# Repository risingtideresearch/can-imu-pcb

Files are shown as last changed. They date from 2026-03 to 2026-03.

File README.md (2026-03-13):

# CAN IMU

A carrier PCB for a Microstrain 3DM-CV7 Inertial Measurement Unit to act as a CAN / NMEA 2000
device.

It is designed to fit in the Hammond [1554E2GY](https://www.hammfg.com/part/1554E2GY) enclosure.

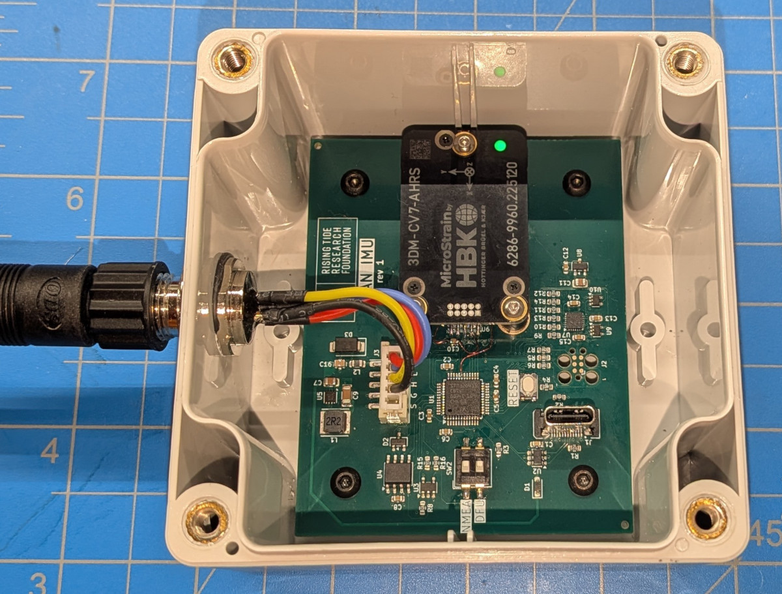
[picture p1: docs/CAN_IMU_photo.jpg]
CAN IMU CANIMU


## Assembly

The BOM can be found [here](output/CAN_IMU_rev1_BOM.csv), and includes most parts, but there are
some additional parts not included there:

- The case: Hammond 1554E2GY
- Brass solderable nuts for securing the microstrain: SMTSOB-256-2ET (qty 3)
- M3x8 screws for securing the PCB in the enclosure (These should ideally be non-ferrous if you care about magnetemeter accuracy) 
- M12 connector: [T4130012051-000](https://www.digikey.com/en/products/detail/te-connectivity-amp-connectors/T4130012051-000/7927438)
- 5-pin PH connector housing for wiring the M12 to the board:
  [PHR-5](https://www.digikey.com/en/products/detail/jst-sales-america-inc/PHR-5/608605) (plus the
  appropriate crimp pins or pre-crimped wires)

## Software

Software for this board can be found in the [can-imu-fw repo](https://github.com/risingtideresearch/can-imu-fw)

# Revision History

## Rev 1

First fabricated January 2026. 

### Errata

- The microstrain IMU connector is backwards (repairable with cut traces and bodge wires)

## Rev 2

Fixes IMU connector pinout. No CPU pin changes, and functionally equivalent to bodged rev1.

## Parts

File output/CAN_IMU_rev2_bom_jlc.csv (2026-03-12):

Designator | Footprint | Quantity | Value | LCSC Part #
C1 | 0603 | 1 | 0.1u | C1590
C10, C12, C13, C14, C15, C2, C3, C4, C5, C6, C8 | 0603 | 11 | 1u | C15849
C11, C7 | 0805 | 2 | 10uF | C15850
C16 | NFM21PC_Feedthrough_Cap | 1 | NFM21PC104R1E3D | C86150
C9 | 1206 | 1 | 22uF | C12891
D1 | D_SOD-323_HandSoldering | 1 | CUS10S30,H3F | C146335
D2 | SOT-23 | 1 | ESD2CANFD24 | C5278878
D3 | D_SMA | 1 | SMAJ17A-13-F | C134963
J1 | USB_C_Receptacle_JAE_DX07S024WJ3R400 | 1 | USB_C_Receptacle_USB2.0_16P | C2896636
J3 | JST_PH_B5B-PH-SM4-TB_1x05-1MP_P2.00mm_Vertical | 1 | Conn_01x05 | C265085
L1 | IND_LQH5BPN2R2NT0L | 1 | 2.2uH | C135262
L2 | 0805 | 1 | MPZ2012S601AT000 | C21519
R1, R10, R11, R12, R13, R14, R16, R2, R9 | 0603 | 9 | 5.1k | C105580
R15, R3, R8 | 0603 | 3 | 47k | C25819
R4, R5, R6, R7 | 0603 | 4 | 100 | C105588
SW1 | SW_SPST_PTS810 | 1 | RST | C221896
SW2 | SW_DIP_SPSTx02_Slide_6.7x6.64mm_W8.61mm_P2.54mm_LowProfile | 1 | SW_DIP_x02 | C3312524
U1 | LQFP-48_7x7mm_P0.5mm | 1 | STM32G431CBTx | C529355
U10, U9 | SOT-353_SC-70-5 | 2 | SN74AUP1T34DCK | C131985
U2 | SOT-23-6 | 1 | USBLC6-2SC6 | C7519
U3 | SOT-23-5 | 1 | SN74LVC1G126DBV | C46472327
U4 | SOIC-8_3.9x4.9mm_P1.27mm | 1 | TCAN3414 | C22396693
U5 | WSON-8-1EP_2x2mm_P0.5mm_EP0.9x1.6mm_ThermalVias | 1 | TPS62172DSG | C59873
U6 | 3DM-CV7 | 1 | ~ | C6659241
U7 | InvenSense_QFN-24_3x3mm_P0.4mm | 1 | ICM-20948 | C726001
U8 | SOT-23 | 1 | MCP1700x-180xxTT | C150796

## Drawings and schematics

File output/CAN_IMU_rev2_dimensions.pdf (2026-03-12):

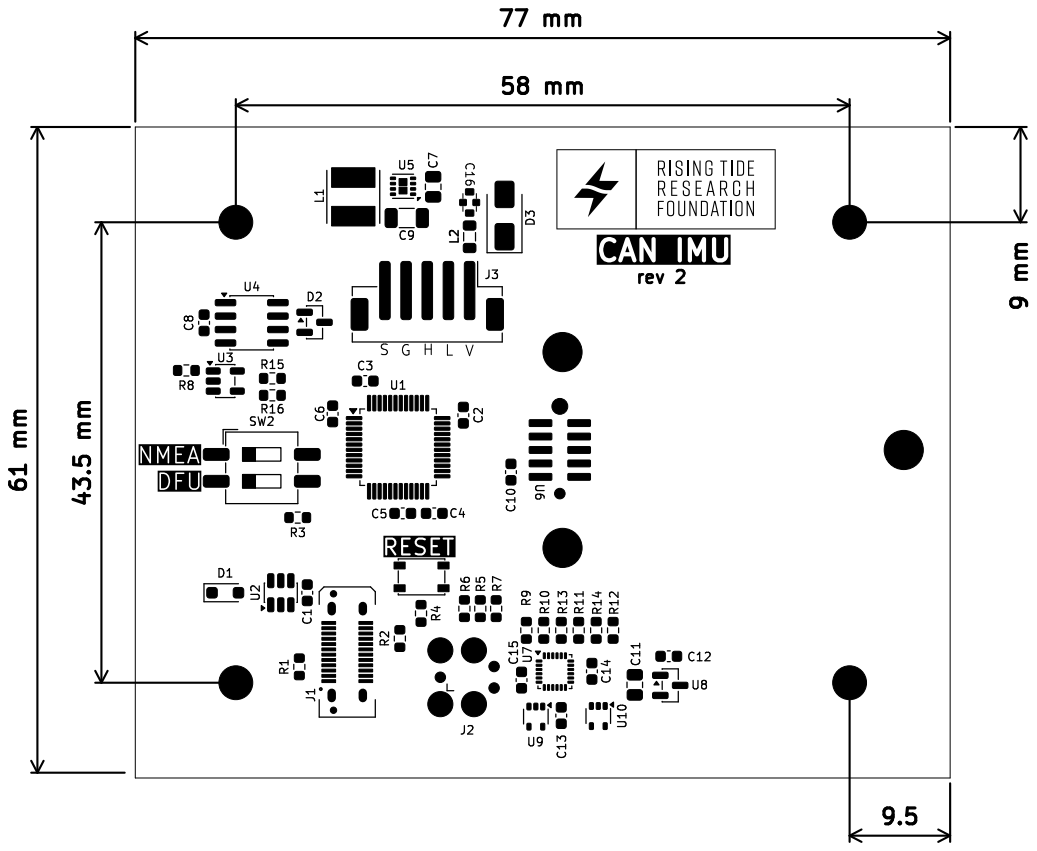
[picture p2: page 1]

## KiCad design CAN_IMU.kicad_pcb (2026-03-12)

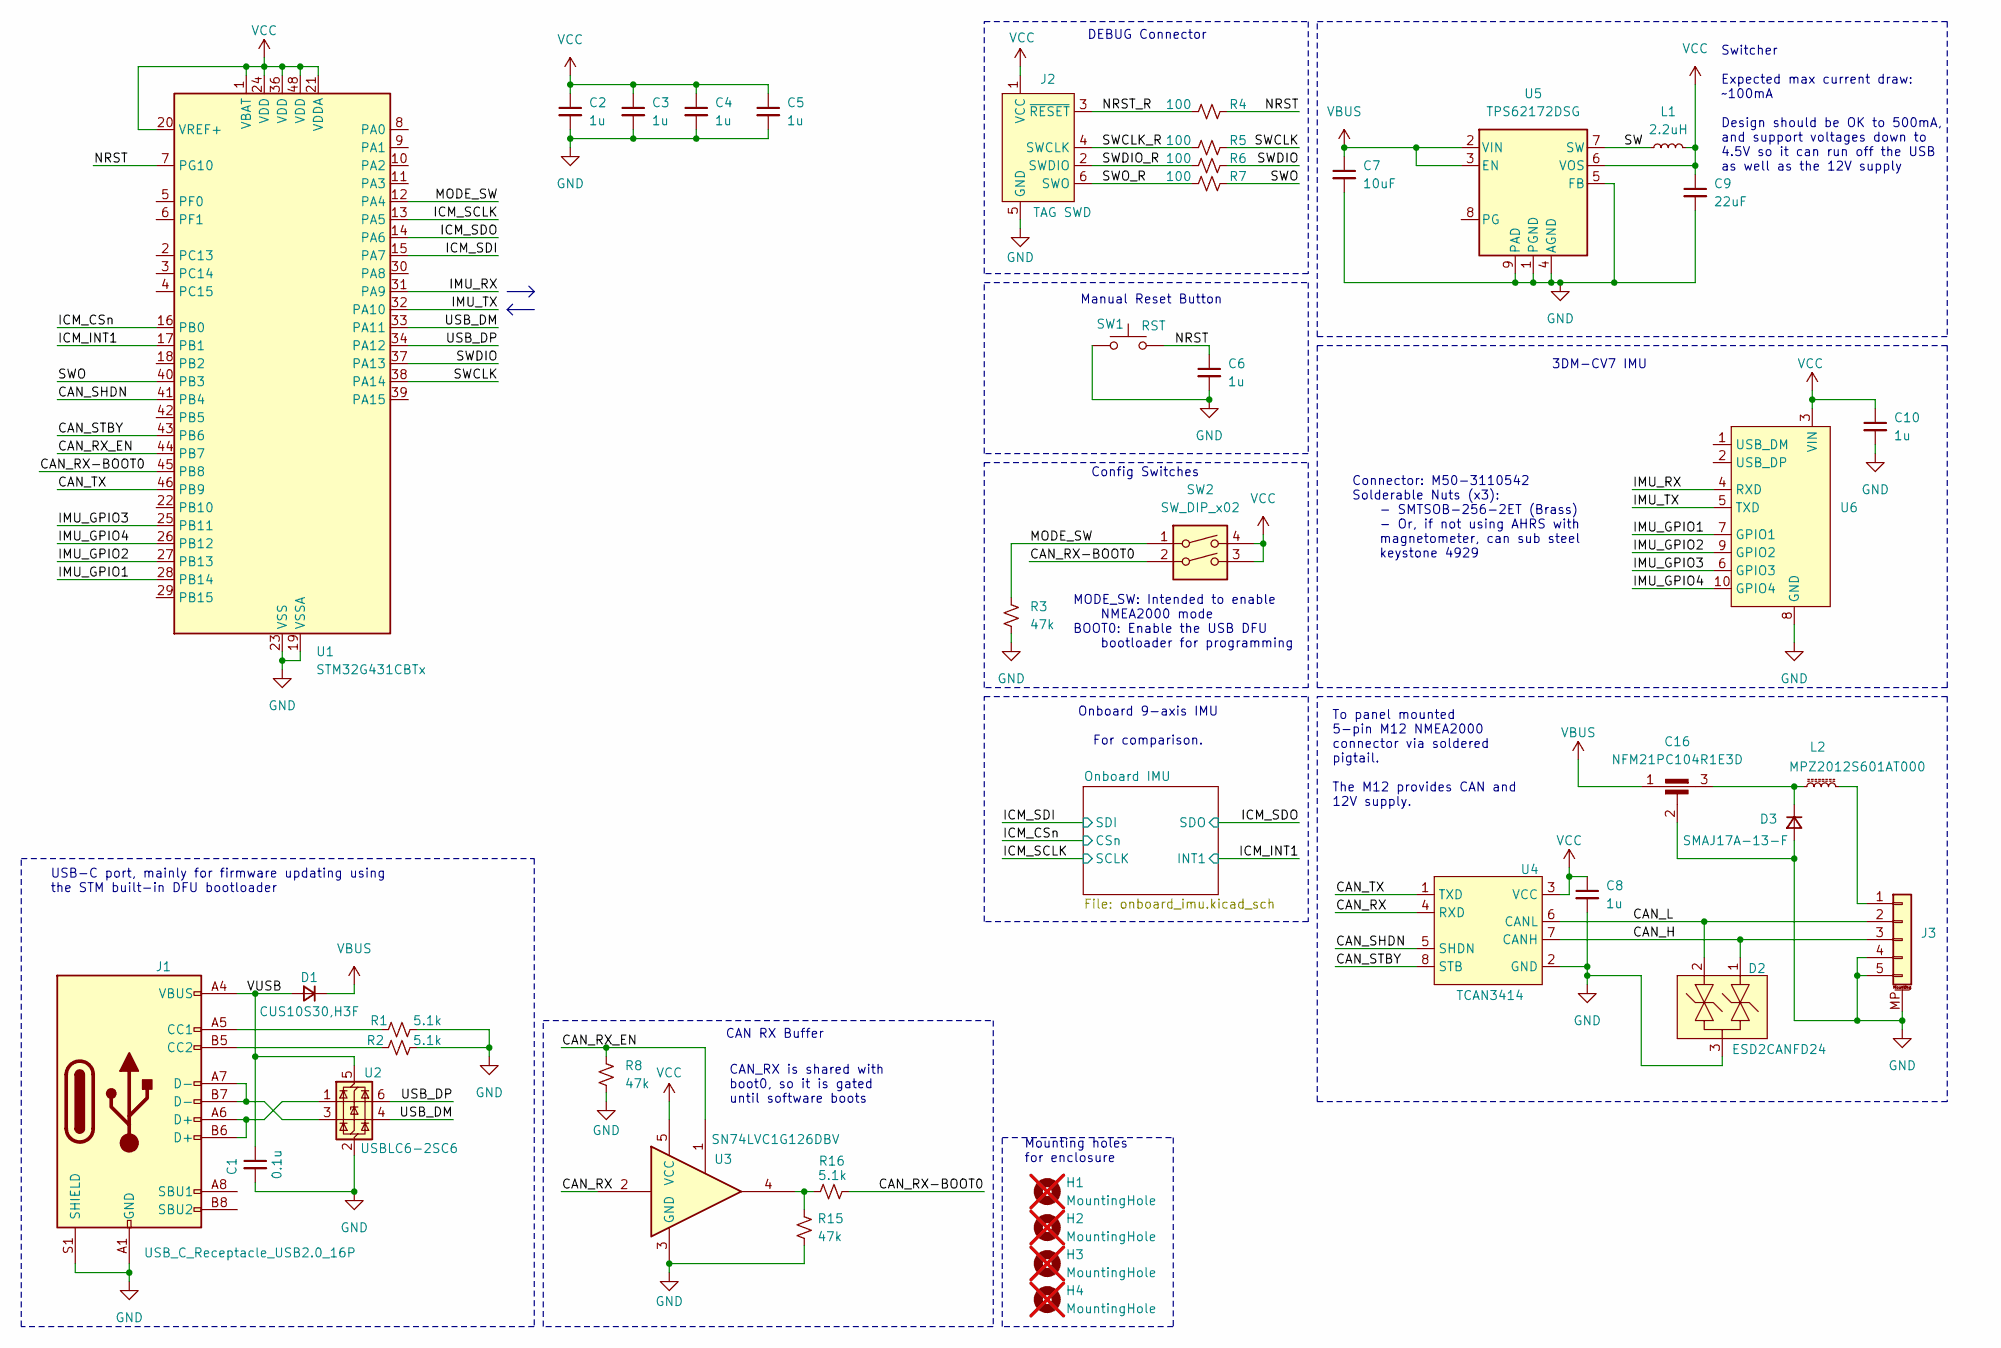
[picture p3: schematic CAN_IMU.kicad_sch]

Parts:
C1: 0.1u; C_0603_1608Metric; Mfg Part Number CL10B104KA8NNNC; LCSC Part Number C1590
C2, C3, C4, C5, C6, C8, C10: 1u; C_0603_1608Metric; Mfg Part Number CL10B105KP8NNNC; Digikey Part Number 1276-1946-1-ND
C7: 10uF; C_0805_2012Metric; Mfg Part Number GRM21BR61H106KE43L; Digikey Part Number 490-18663-1-ND
C9: 22uF; C_1206_3216Metric; Mfg Part Number CL31A226KAHNNNE; Digikey Part Number 1276-3047-1-ND
C16: NFM21PC104R1E3D; NFM21PC_Feedthrough_Cap; Mfg Part Number NFM21PC104R1E3D; LCSC Part Number C86150
D1: CUS10S30,H3F; D_SOD-323_HandSoldering; Mfg Part Number CUS10S30,H3F; Digikey Part Number CUS10S30H3FCT-ND
D2: ESD2CANFD24; SOT-23; Mfg Part Number ESD2CANFD24; Digikey Part Number 1727-PESD2CANFD24UU-QXCT-ND
D3: SMAJ17A-13-F; D_SMA; Mfg Part Number SMAJ17A-13-F; Digikey Part Number SMAJ17A-FDICT-ND
H1, H2, H3, H4: MountingHole; MountingHole_3.2mm_M3; not fitted
J1: USB_C_Receptacle_USB2.0_16P; USB_C_Receptacle_JAE_DX07S024WJ3R400; Mfg Part Number DX07S024WJ3R400; Digikey Part Number 670-2950-1-ND
J2: TAG SWD; Tag-Connect_TC2030-IDC-FP_2x03_P1.27mm_Vertical
J3: Conn_01x05; JST_PH_B5B-PH-SM4-TB_1x05-1MP_P2.00mm_Vertical; Mfg Part Number B5B-PH-SM4-TB; Digikey Part Number 455-B5B-PH-SM4-TBCT-ND
L1: 2.2uH; IND_LQH5BPN2R2NT0L; Mfg Part Number LQH5BPN2R2NT0L; Digikey Part Number 490-7778-1-ND
L2: MPZ2012S601AT000; L_0805_2012Metric; Mfg Part Number MPZ2012S601AT000; Digikey Part Number 445-MPZ2012S601AT000CT-ND
R1, R2, R16: 5.1k; R_0603_1608Metric; Mfg Part Number RC0603FR-075K1L; LCSC Part Number C105580
R3, R8, R15: 47k; R_0603_1608Metric; Mfg Part Number RC0603FR-0747KL; Digikey Part Number 311-47.0KHRCT-ND
R4, R5, R6, R7: 100; R_0603_1608Metric; Mfg Part Number RC0603FR-07100RL; Digikey Part Number 311-100HRCT-ND
SW1: RST; SW_SPST_PTS810; Mfg Part Number PTS810SJK250SMTRLFS; LCSC Part Number C221896
SW2: SW_DIP_x02; SW_DIP_SPSTx02_Slide_6.7x6.64mm_W8.61mm_P2.54mm_LowProfile; Mfg Part Number DS04-254-2-02BK-SMT-TR; Digikey Part Number 2223-DS04-254-2-02BK-SMT-CT-ND
U1: STM32G431CBTx; LQFP-48_7x7mm_P0.5mm; Mfg Part Number STM32G431CBT6; Digikey Part Number 497-19473-ND
U2: USBLC6-2SC6; SOT-23-6; Mfg Part Number USBLC6-2SC6; LCSC Part Number C7519
U3: SN74LVC1G126DBV; SOT-23-5; Mfg Part Number SN74LVC1G126DBVR; Digikey Part Number 296-11605-1-ND
U4: TCAN3414; SOIC-8_3.9x4.9mm_P1.27mm; Mfg Part Number TCAN3414DR; Digikey Part Number 296-TCAN3414DRCT-ND
U5: TPS62172DSG; WSON-8-1EP_2x2mm_P0.5mm_EP0.9x1.6mm_ThermalVias; Mfg Part Number TPS62172DSGR; Digikey Part Number 296-39449-1-ND
U6: 3DM-CV7; Mfg Part Number M50-3110542; Digikey Part Number 952-2342-ND

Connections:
/CAN_H: D2.1, J3.3, U4.7 (CANH)
/CAN_L: D2.2, J3.2, U4.6 (CANL)
/CAN_RX: U3.2, U4.4 (RXD)
/CAN_RX-BOOT0: R16.1, SW2.2, U1.45 (PB8)
/CAN_RX_EN: R8.1, U1.44 (PB7), U3.1
/CAN_SHDN: U1.41 (PB4), U4.5 (SHDN)
/CAN_STBY: U1.43 (PB6), U4.8 (STB)
/CAN_TX: U1.46 (PB9), U4.1 (TXD)
/ICM_CSn: U1.16 (PB0); also elsewhere on the board
/ICM_INT1: U1.17 (PB1); also elsewhere on the board
/ICM_SCLK: U1.13 (PA5); also elsewhere on the board
/ICM_SDI: U1.15 (PA7); also elsewhere on the board
/ICM_SDO: U1.14 (PA6); also elsewhere on the board
/IMU_GPIO1: U1.28 (PB14), U6.7 (GPIO1)
/IMU_GPIO2: U1.27 (PB13), U6.9 (GPIO2)
/IMU_GPIO3: U1.25 (PB11), U6.6 (GPIO3)
/IMU_GPIO4: U1.26 (PB12), U6.10 (GPIO4)
/IMU_RX: U1.31 (PA9), U6.4 (RXD)
/IMU_TX: U1.32 (PA10), U6.5 (TXD)
/MODE_SW: R3.1, SW2.1, U1.12 (PA4)
/NRST: C6.1, R4.1, SW1.2, U1.7 (PG10)
/NRST_R: J2.3 (~RESET), R4.2
/SW: L1.1, U5.7 (SW)
/SWCLK: R5.1, U1.38 (PA14)
/SWCLK_R: J2.4 (SWCLK), R5.2
/SWDIO: R6.1, U1.37 (PA13)
/SWDIO_R: J2.2 (SWDIO), R6.2
/SWO: R7.1, U1.40 (PB3)
/SWO_R: J2.6 (SWO), R7.2
/USB_DM: U1.33 (PA11), U2.4 (I/O2)
/USB_DP: U1.34 (PA12), U2.6 (I/O1)
/VUSB: C1.1, D1.2 (A), J1.A4 (VBUS), J1.A9 (VBUS), J1.B4 (VBUS), J1.B9 (VBUS), U2.5 (VBUS)
GND: C1.2, C2.2, C3.2, C4.2, C5.2, C6.2, C7.2, C8.2, C9.2, C10.2, C16.2, D2.3, D3.2 (A), J1.A1 (GND), J1.A12 (GND), J1.B1 (GND), J1.B12 (GND), J1.S1 (SHIELD), J2.5 (GND), J3.4, J3.5, J3.MP (MountPin), R1.1, R2.1, R3.2, R8.2, R15.2, SW1.1, U1.19 (VSSA), U1.23 (VSS), U1.35 (VSS), U1.47 (VSS), U2.2 (GND), U3.3 (GND), U4.2 (GND), U5.1 (PGND), U5.4 (AGND), U5.5 (FB), U5.9 (PAD), U6.8 (GND); also elsewhere on the board
unnamed: C16.3, D3.1 (K), L2.1
unnamed: J1.A5 (CC1), R1.2
unnamed: J1.B5 (CC2), R2.2
unnamed: J1.A6 (D+), J1.B6 (D+), U2.1 (I/O1)
unnamed: J1.A7 (D-), J1.B7 (D-), U2.3 (I/O2)
unnamed: J3.1, L2.2
unnamed: R15.1, R16.2, U3.4
VBUS: C7.1, C16.1, D1.1 (K), U5.2 (VIN), U5.3 (EN)
VCC: C2.1, C3.1, C4.1, C5.1, C8.1, C9.1, C10.1, J2.1 (VCC), L1.2, SW2.3, SW2.4, U1.1 (VBAT), U1.20 (VREF+), U1.21 (VDDA), U1.24 (VDD), U1.36 (VDD), U1.48 (VDD), U3.5 (VCC), U4.3 (VCC), U5.6 (VOS), U6.3 (VIN); also elsewhere on the board

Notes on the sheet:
DEBUG Connector
Mounting holes for enclosure
To panel mounted 5-pin M12 NMEA2000 connector via soldered pigtail. The M12 provides CAN and 12V supply.
Connector: M50-3110542 Solderable Nuts (x3): - SMTSOB-256-2ET (Brass) - Or, if not using AHRS with magnetometer, can sub steel keystone 4929
CAN RX Buffer
3DM-CV7 IMU
Manual Reset Button
Onboard 9-axis IMU For comparison.
CAN_RX is shared with boot0, so it is gated until software boots
MODE_SW: Intended to enable NMEA2000 mode BOOT0: Enable the USB DFU bootloader for programming
Switcher Expected max current draw: ~100mA Design should be OK to 500mA, and support voltages down to 4.5V so it can run off the USB as well as the 12V supply
USB-C port, mainly for firmware updating using the STM built-in DFU bootloader
Config Switches

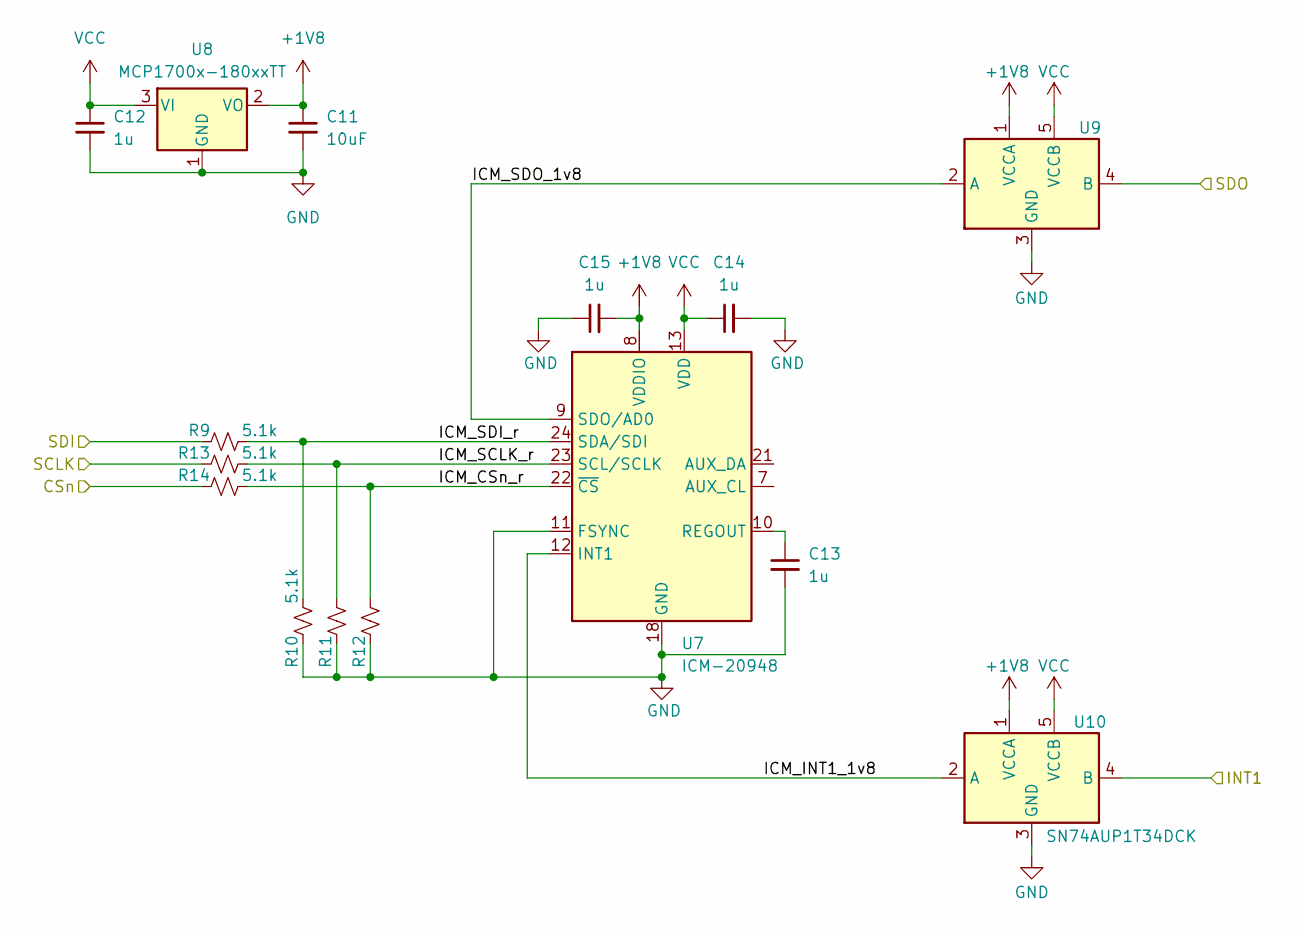
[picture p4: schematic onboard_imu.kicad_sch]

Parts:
C11: 10uF; C_0805_2012Metric; Mfg Part Number GRM21BR61H106KE43L; Digikey Part Number 490-18663-1-ND
C12, C13, C14, C15: 1u; C_0603_1608Metric; Mfg Part Number CL10B105KP8NNNC; Digikey Part Number 1276-1946-1-ND
R9, R10, R11, R12, R13, R14: 5.1k; R_0603_1608Metric; Mfg Part Number RC0603FR-075K1L; LCSC Part Number C105580
U7: ICM-20948; InvenSense_QFN-24_3x3mm_P0.4mm; Mfg Part Number ICM-20948; Digikey Part Number 1428-1123-1-ND
U8: MCP1700x-180xxTT; SOT-23; Mfg Part Number MCP1700T-1802E/TT; Digikey Part Number MCP1700T1802ETTCT-ND
U9, U10: SN74AUP1T34DCK; SOT-353_SC-70-5; Mfg Part Number SN74AUP1T34DCKR; Digikey Part Number 296-34900-1-ND

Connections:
+1V8: C11.1, C15.2, U7.8 (VDDIO), U8.2 (VO), U9.1 (VCCA), U10.1 (VCCA)
/ICM_CSn: R14.2; also elsewhere on the board
/ICM_INT1: U10.4 (B); also elsewhere on the board
/ICM_SCLK: R13.2; also elsewhere on the board
/ICM_SDI: R9.2; also elsewhere on the board
/ICM_SDO: U9.4 (B); also elsewhere on the board
/Onboard IMU/ICM_CSn_r: R12.1, R14.1, U7.22 (~CS)
/Onboard IMU/ICM_INT1_1v8: U7.12 (INT1), U10.2 (A)
/Onboard IMU/ICM_SCLK_r: R11.1, R13.1, U7.23 (SCL/SCLK)
/Onboard IMU/ICM_SDI_r: R9.1, R10.1, U7.24 (SDA/SDI)
/Onboard IMU/ICM_SDO_1v8: U7.9 (SDO/AD0), U9.2 (A)
GND: C11.2, C12.2, C13.2, C14.2, C15.1, R10.2, R11.2, R12.2, U7.11 (FSYNC), U7.18 (GND), U7.20 (GND), U8.1 (GND), U9.3 (GND), U10.3 (GND); also elsewhere on the board
unnamed: C13.1, U7.10 (REGOUT)
VCC: C12.1, C14.1, U7.13 (VDD), U8.3 (VI), U9.5 (VCCB), U10.5 (VCCB); also elsewhere on the board

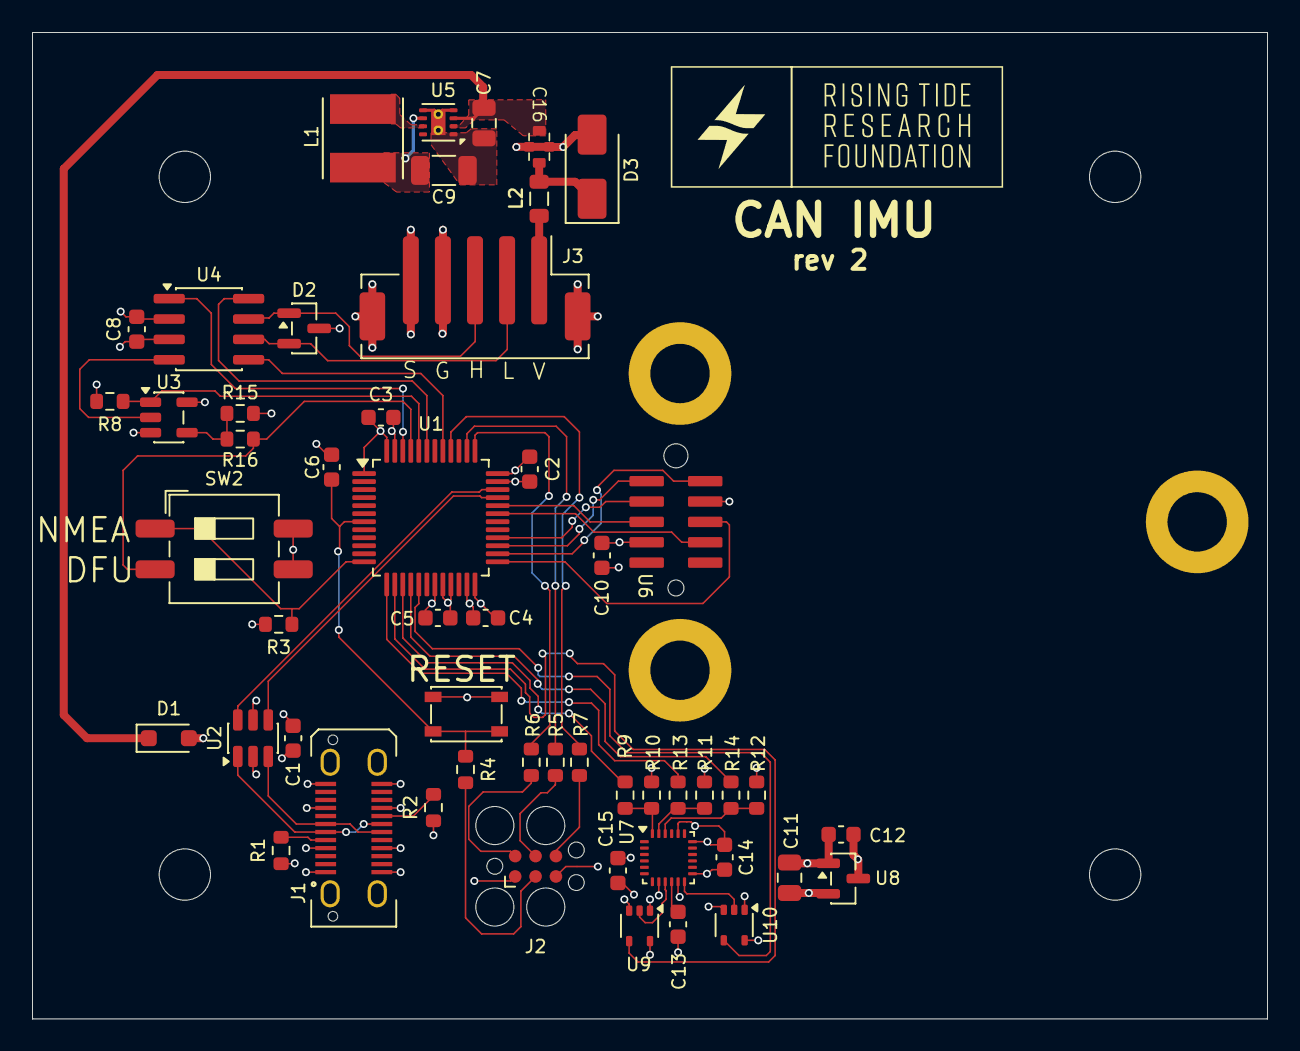
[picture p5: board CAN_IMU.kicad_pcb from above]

Board: 4 copper layers, 77.0 x 61.5 mm, 56 parts (0 on the bottom side), 49 nets.

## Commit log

2025-12-17 Schematic more or less complete
    [CAN_IMU.kicad_pcb, CAN_IMU.kicad_sch]
2025-12-17 Add pulldown to CAN_RX_EN
    [CAN_IMU.kicad_sch]
2025-12-17 Basically finished layout
    [CAN_IMU.kicad_pcb, CAN_IMU.kicad_sch]
2025-12-17 Add 3D models for connectors
    [CAN_IMU.kicad_pcb]
2025-12-23 Add part numbers and output generation
    [CAN_IMU.kicad_sch]
2025-12-24 Add onboard IMU and logo
    [CAN_IMU.kicad_pcb, CAN_IMU.kicad_sch, onboard_imu.kicad_sch]
2026-01-02 Add pull-down and series resistor to CAN_RX
    Prevent shorting the buffer output when throwing the DIP switch
    [CAN_IMU.kicad_pcb, CAN_IMU.kicad_sch]
2026-01-02 Add rev1 output files
    [CAN_IMU-B_Cu.gbr, CAN_IMU-B_Mask.gbr, CAN_IMU-B_Paste.gbr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]
2026-01-20 Fix some missing part numbers and update BOM
    No artwork changes.
    [CAN_IMU.kicad_pcb, CAN_IMU.kicad_sch, CAN_IMU_rev1_BOM.csv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]
2026-03-12 Rev 2 updates
    - Fix microstrain connector pinout
    - Update silkscreen rev
    [CAN_IMU.kicad_pcb, CAN_IMU.kicad_sch]
2026-03-12 Fix DRC errors
    - Move refdes for moved capacitor
    [CAN_IMU.kicad_pcb]
2026-03-12 rev2 outputs
    [CAN_IMU-B_Cu.gbr, CAN_IMU-B_Mask.gbr, CAN_IMU-B_Paste.gbr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]
